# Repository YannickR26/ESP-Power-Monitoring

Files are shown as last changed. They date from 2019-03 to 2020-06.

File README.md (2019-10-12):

# ESP-Power-Monitoring
Power Monitoring based on ESP8266 and ATM90E32

## Hardware
ATM90E32 is a poly-phase energy metering ic, so 3 lines can be monitor

This board can be work in 2 mode :
  
  * 1 phase mode : 110V to 240V AC (up to 3 line)
  * 3 phase mode : 380V AC (use the 3 line)
 
[Here the schematic of this board](Hardware/Project%20Outputs%20for%20ESP-Power-Monitoring/Schematic%20Print/Schematic%20Prints.PDF)

And some pictures of this board

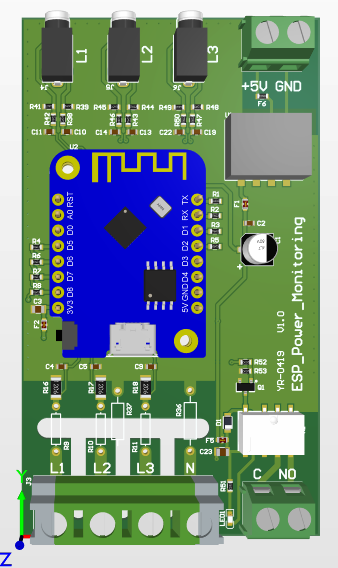
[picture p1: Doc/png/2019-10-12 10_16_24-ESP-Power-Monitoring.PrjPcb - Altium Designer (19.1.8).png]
top


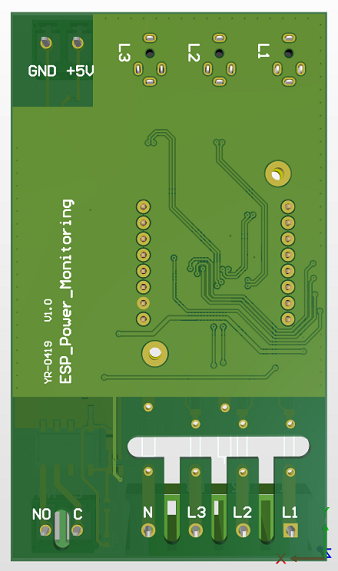
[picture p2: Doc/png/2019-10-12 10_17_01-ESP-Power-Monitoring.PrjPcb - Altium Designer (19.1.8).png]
bottom


This board can be mount on DIN rail

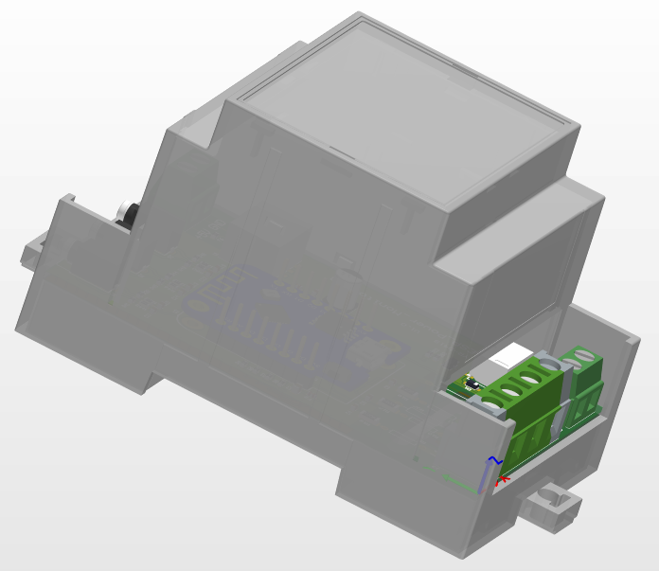
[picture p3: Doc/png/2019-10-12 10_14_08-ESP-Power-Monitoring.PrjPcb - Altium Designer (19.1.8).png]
din rail enclosure


## Software
Send data in MQTT at a fix configurable time

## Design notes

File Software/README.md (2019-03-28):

# ESP-Power-Monitoring
Power Monitoring based on ESP8266

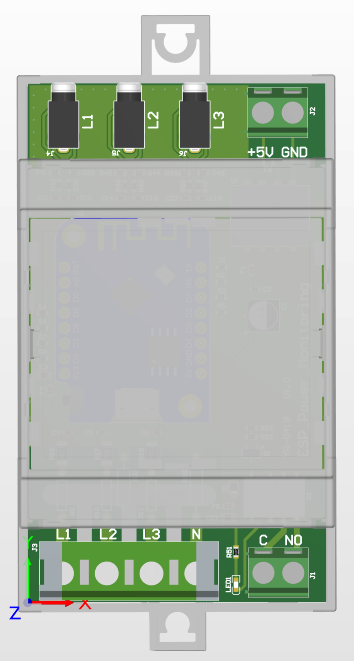
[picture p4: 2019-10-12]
Doc/png/2019-10-12 10_15_19-ESP-Power-Monitoring.PrjPcb - Altium Designer (19.1.8).png

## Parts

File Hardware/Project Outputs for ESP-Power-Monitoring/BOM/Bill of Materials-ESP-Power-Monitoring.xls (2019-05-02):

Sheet: BOM Report
Bill of Materials |  | Bill of Materials for Project [ESP-Power-Monitoring.PrjPcb] (No PCB Document Selected)
Source Data From: |  | ESP-Power-Monitoring.PrjPcb
Project: |  | ESP-Power-Monitoring.PrjPcb
Variant: |  | None
Creation Date: | 23/04/2019 | 9:58:00
Print Date: | 2019-04-23 | 10:09:58
Production Quantity: | 1
Currency | Euros (€)
Footprint | Comment | Designator | Quantity | Supplier 1 | Supplier Part Number 1 | Supplier Pricing 1 | Subtotal | MF | MPN | Farnell | Digi-Key
 | Boitier Rail DIN | B1 | 1 | Farnell | 2473160 | 3,62 € | 3.620 € | BUD INDUSTRIES | DMB4771 | 5
CAP_PANA_C | 100uF_10V_PANA_C | C1 | 1 | Farnell | 2807991 | 0,274 € | 0.274 € | PANASONIC ELECTRONIC COMPONENTS | EEE1AA101WR | 5
C0603 | 1uF_16V_0603 | C2 | 1 | Farnell | 2533943 | 0,0886€ | 0.089 € | WURTH ELEKTRONIK | 885012106017 | 10
C0805 | 10uF_6V3_0805 | C3, C12, C16, C17, C20, C21, C23 | 7 | Farnell | 1759476 | 0,28 € | 1.960 € | MULTICOMP | MCTT21X106M6R3CT | 40
C0603 | 18nF_16V_0603 | C4, C5, C6, C7, C8, C9, C10, C11, C13, C14, C19, C22 | 12 | Farnell | 1759006 | 0,0444 € | 0.533 € | MULTICOMP | MC0603B183K160CT | 60
C0603 | 100nF_10V_0603 | C15, C18 | 2 | Farnell | 2627427 | 0,0486 € | 0.097 € | MULTICOMP | MC0603B104K100CT | 10
TUMD2 | 100V_1A_TUMD2 | D1 | 1 | Farnell | 1864881 | 0,252€ | 0.252 € | VISHAY | MSE1PB-M3/89A | 5
EMIFIL_0603 | EMI | F1, F3, F4, F5, F6 | 5 | Farnell | 1686508 | 0,083 € | 0.415 € | MURATA | NFM18PC104R1C3D | 25
R0603 | 1A | F2 | 1 | Farnell | 2849996 | 0,101 € | 0.101 € | MULTICOMP | MCCFB0603TFF/1 | 10
691213710002 | 691213710002 | J1, J2 | 2 | Farnell | 2493614 | 0,308 € | 0.616 € | Wurth Elektronik | 691213710002 | 10
691242910004 | 691242910004 | J3 | 1 | Farnell | 2493618 | 0,839 € | 0.839 € | Wurth Elektronik | 691242910004 | 10
SJ1-2503A | SJ1-2503A | J4, J5, J6 | 3 | Digi-Key | CP1-2503A-ND | 0,60 € | 1.800 € | CUI Inc. | SJ1-2503A |  | 1
RELAY_G6K_2F_Y | Relay-DPDT | K1 | 1 | Digi-Key | Z2354-ND | 3,43 € | 3.430 € | Omron Electronics | G6K-2F-Y DC3 |  | 5
LED_0603_Bright Green | LED_Green | LED1 | 1 | Farnell | 2322073 | 0,189€ | 0.189 € | Wurth Elektronik | 150060VS75000 | 5
SOT23_N | 2.1A_40V_0R095 | Q1 | 1 | Farnell | 2469648 | 0,342€ | 0.342 € | NEXPERIA | PMV130ENEA | 5
R0603 | 22R_1%_0603 | R1, R2, R3, R4, R5, R6, R7, R8 | 8 | Farnell | 2447301 | 0,0056€ | 0.045 € | Multicomp | MCWR06X22R0FTL | 100
AXIAL-0.3 | 1M_1%_TRAD | R9, R11, R13 | 3 | Farnell | 1100281 | 0,102 € | 0.306 € | TT ELECTRONICS / WELWYN | MH25-1MJI | 20
R1206 | 1K_1%_1206 | R10, R12, R14 | 3 | Farnell | 9337008 | 0,0119 € | 0.036 € | MULTICOMP | MC0125W120651K | 20
R0603 | 1K_1%_0603 | R15, R16, R19, R20, R24, R25, R28, R29, R32 | 9 | Farnell | 1469740 | 0,0211€ | 0.190 € | VISHAY | CRCW06031K00FKEA | 100
AXIAL-0.4 | NC | R17, R18 | 2 |  |  |  | 0.000 €
R0603 | 2R4_1%_0603 | R21, R23, R26, R27, R30, R31 | 6 | Farnell | 2668257 | 0,0529 € | 0.317 € | WALSIN | WR06W2R40FTL | 30
R0603 | 10K_1%_0603 | R22, R35 | 2 | Farnell | 2447230 | 0,0056€ | 0.011 € | MULTICOMP | MCWR06X1002FTL | 100
R0603 | 220R_1%_0603 | R33, R34 | 2 | Farnell | 2447298 | 0,0059 € | 0.012 € | MULTICOMP | MCWR06X2200FTL | 100
R1SE | DC/DC_ISO | U1 | 1 | Farnell | 2484118 | 6,95 € | 6.950 € | XP POWER | ISH0503A |  | 5
WEMOS_D1_MINI | Wemos_D1_Mini | U2 | 1 |  |  |  | 0.000 €
TQFP48 | ATM90E32AS | U3 | 1 | Farnell | 2857740 | 2,17 € | 2.170 € | MICROCHIP | ATM90E32AS-AU-R | 5
OSC_3.2X2.5 | 16.384MHz | Y1 | 1 | Farnell | 2853939 | 0,159€ | 0.159 € | MULTICOMP | MCSJK-7U-16.384-10-30-80-B-30 | 5
Total |  |  | 79 |  |  |  | 24.752 €
Approved |  | Notes

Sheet: Project Information
Project Full Path | D:\Git\mle-ModuleIPCan\Hard\V1.2\Project\ModuleIPCan\ModuleIPCan.PrjPcb
Project Filename | ModuleIPCan.PrjPcb
Variant Name | None
Data-Source Filename | ModuleIPCan.PrjPcb
Data-Source Full Path | D:\Git\mle-ModuleIPCan\Hard\V1.2\Project\ModuleIPCan\ModuleIPCan.PrjPcb
Title | Top
Total Quantity | 268
Report Time | 16:41:35
Report Date | 27/09/2016
Report Date & Tine | 27/09/2016 16:41:35
Output Name | Bill of Materials
Output Type | BOM_PartType
Output Generator Name | BOM
Output Generator Description | Bill of Materials

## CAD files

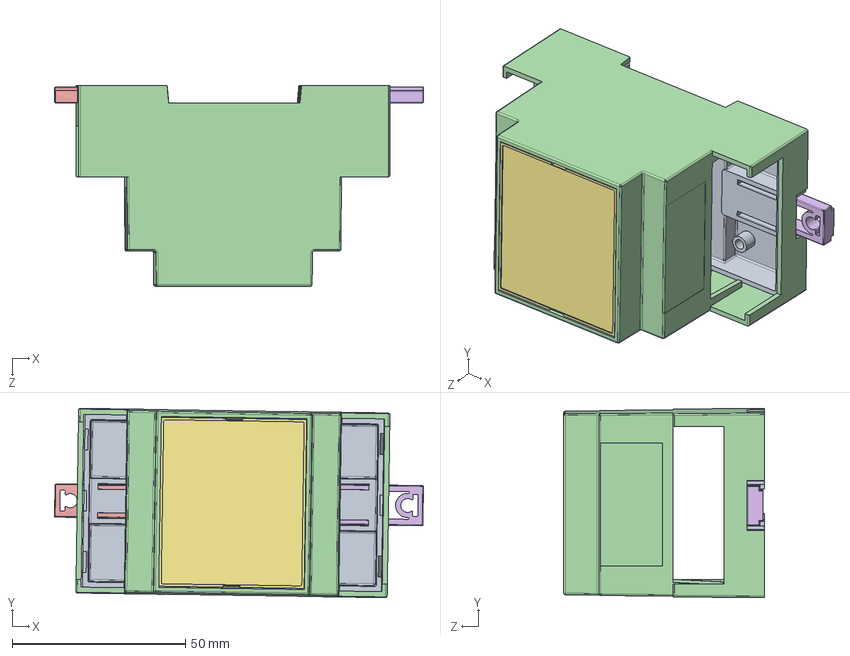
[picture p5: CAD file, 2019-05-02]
Hardware/cnmb_3_kit.STEP
106.6 x 54.7 x 58.0 mm
cnmb_3_kit_01
cnmb_3_kit_02
cnmb_3_kit_03
cnmb_3_kit_04
cnmb_3_kit_05
cnmb_3_kit_06
cnmb_3_kit_07
cnmb_3_kit_08
cnmb_3_kit_09
cnmb_3_kit_10
cnmb_3_kit_13

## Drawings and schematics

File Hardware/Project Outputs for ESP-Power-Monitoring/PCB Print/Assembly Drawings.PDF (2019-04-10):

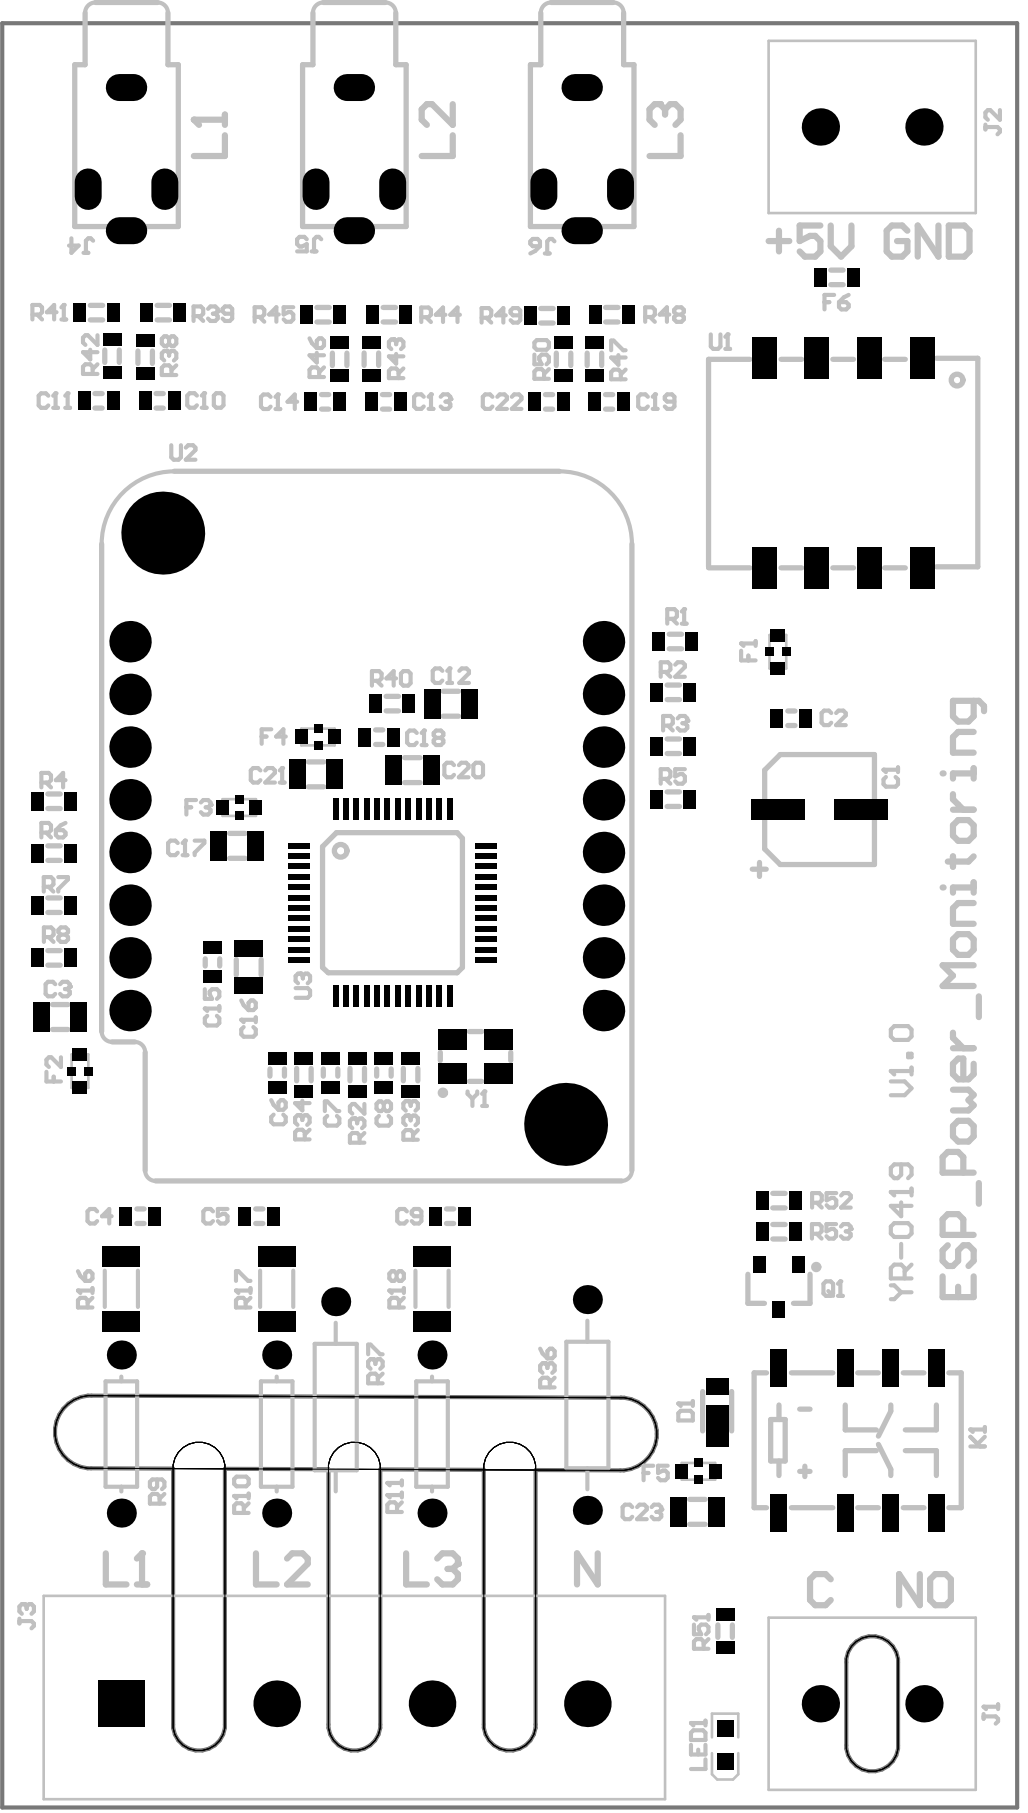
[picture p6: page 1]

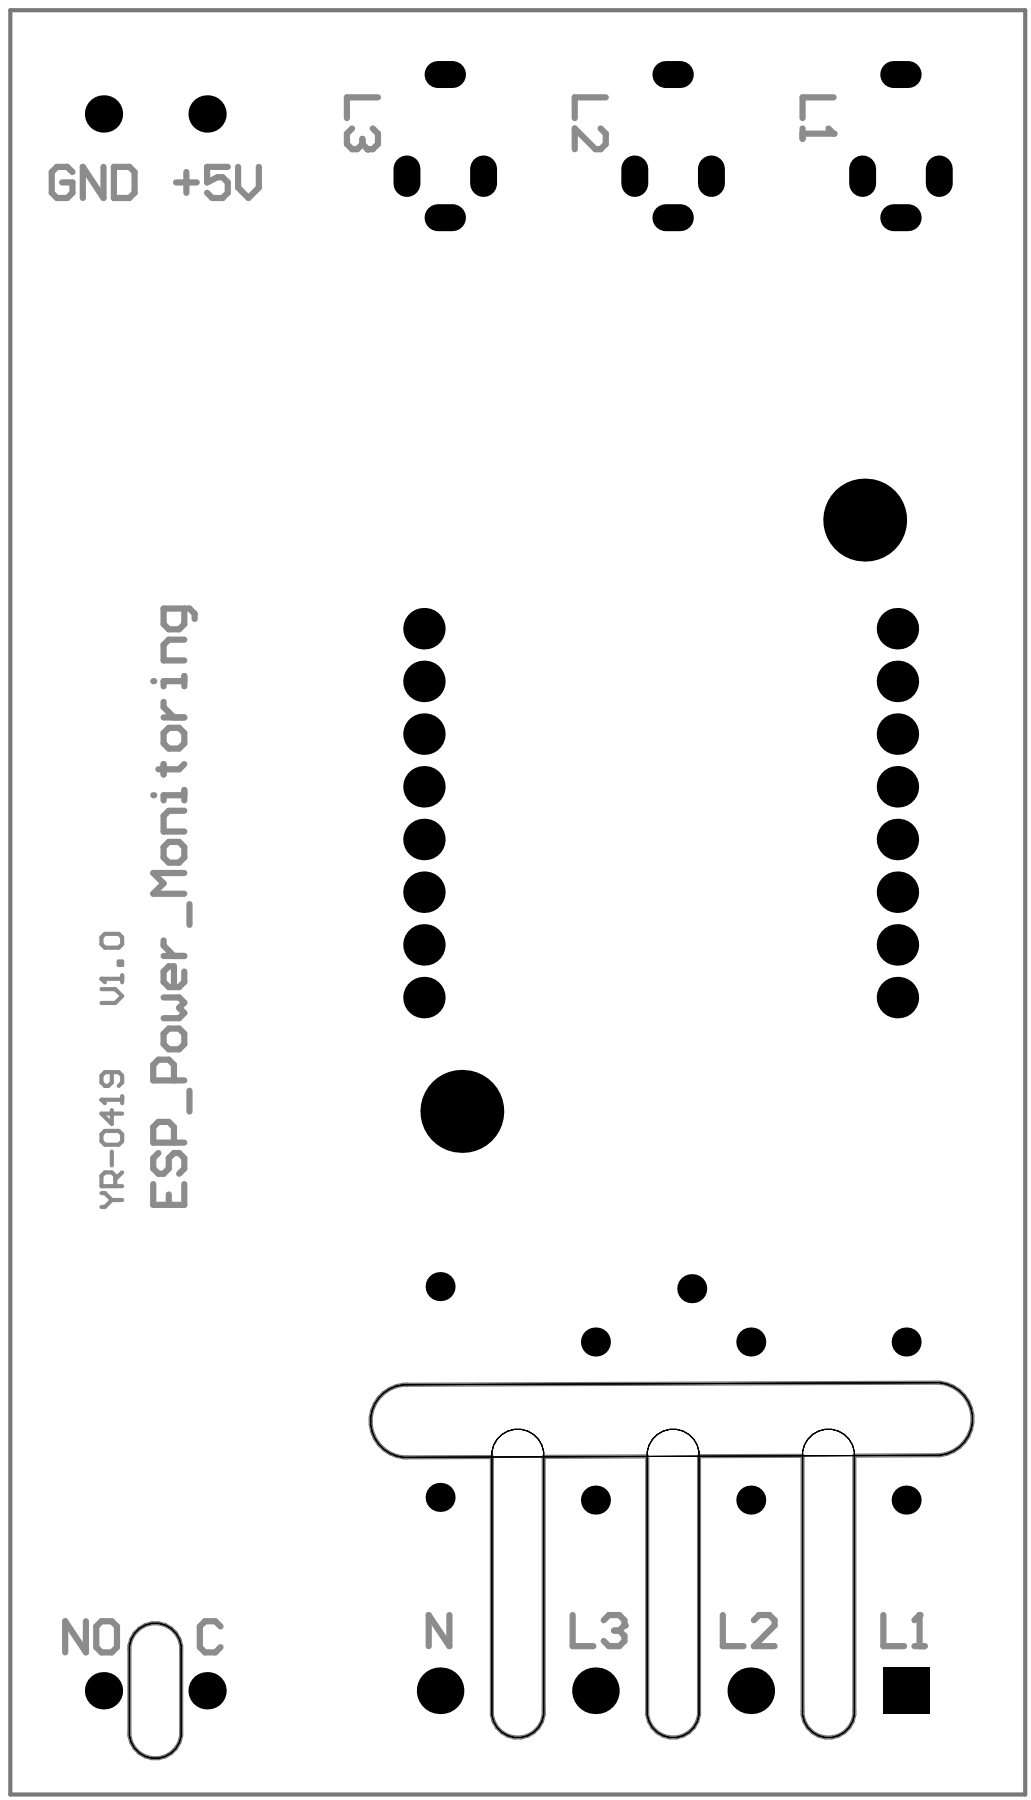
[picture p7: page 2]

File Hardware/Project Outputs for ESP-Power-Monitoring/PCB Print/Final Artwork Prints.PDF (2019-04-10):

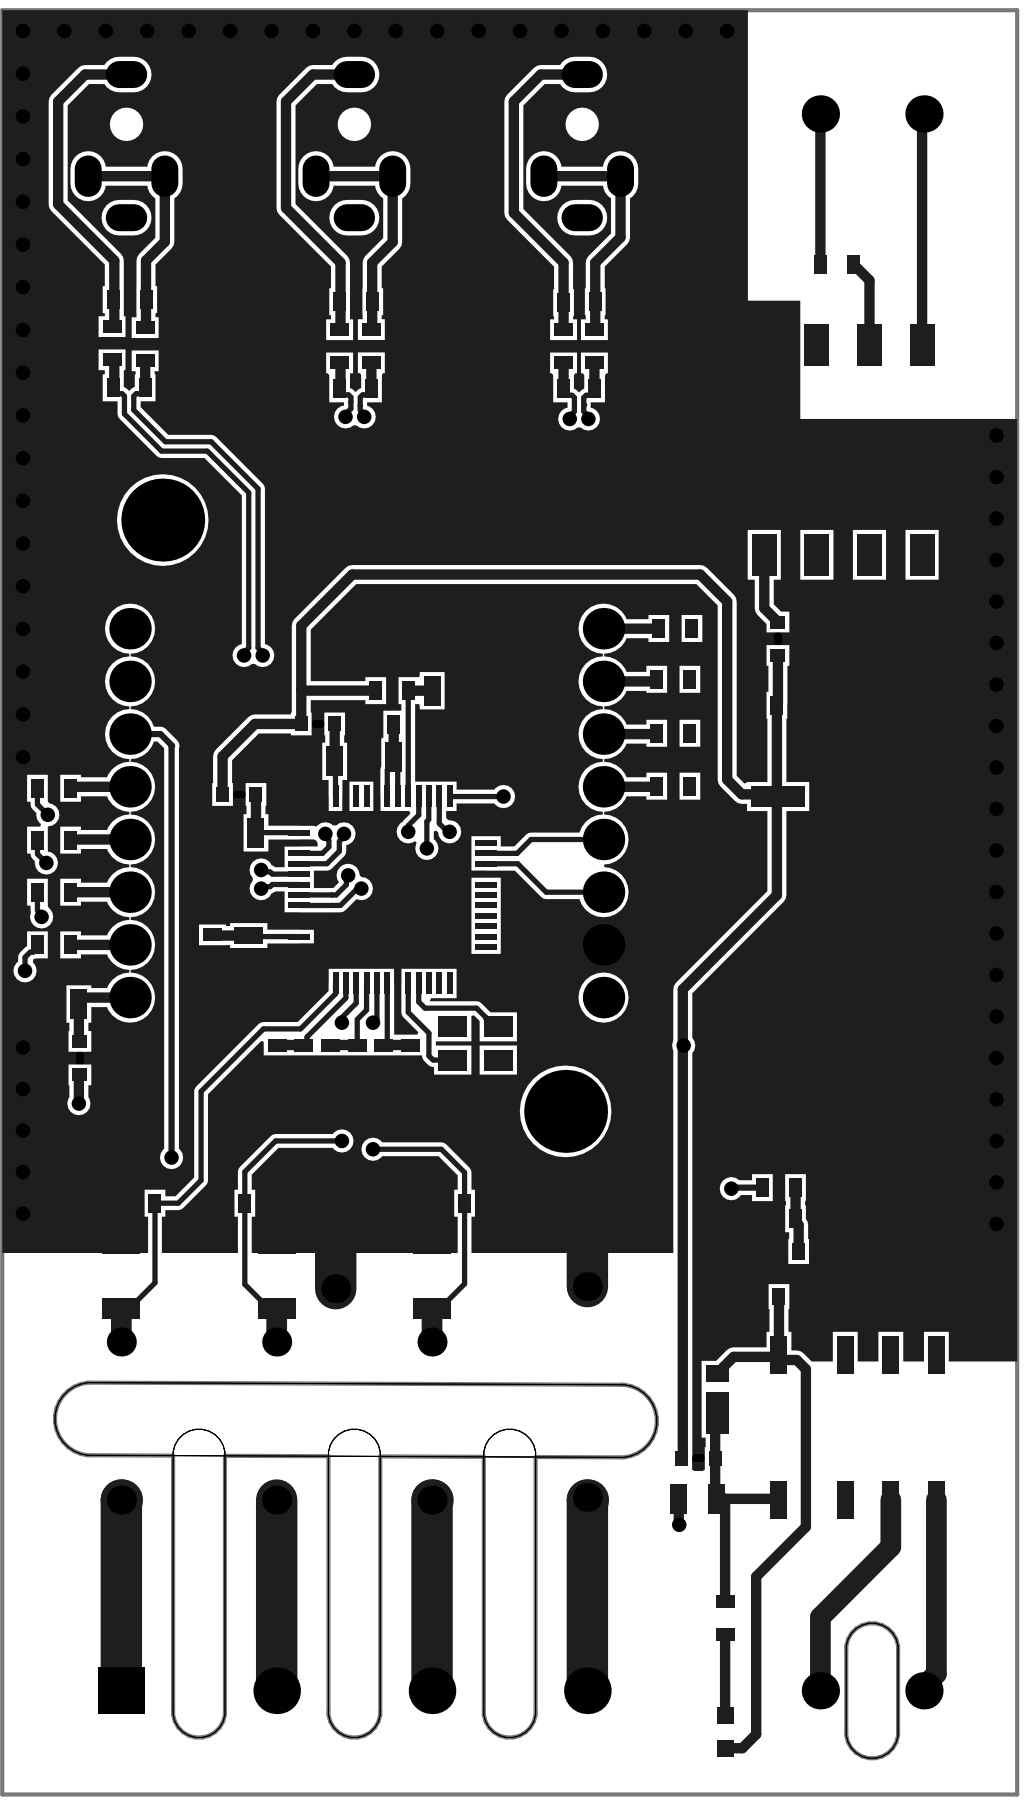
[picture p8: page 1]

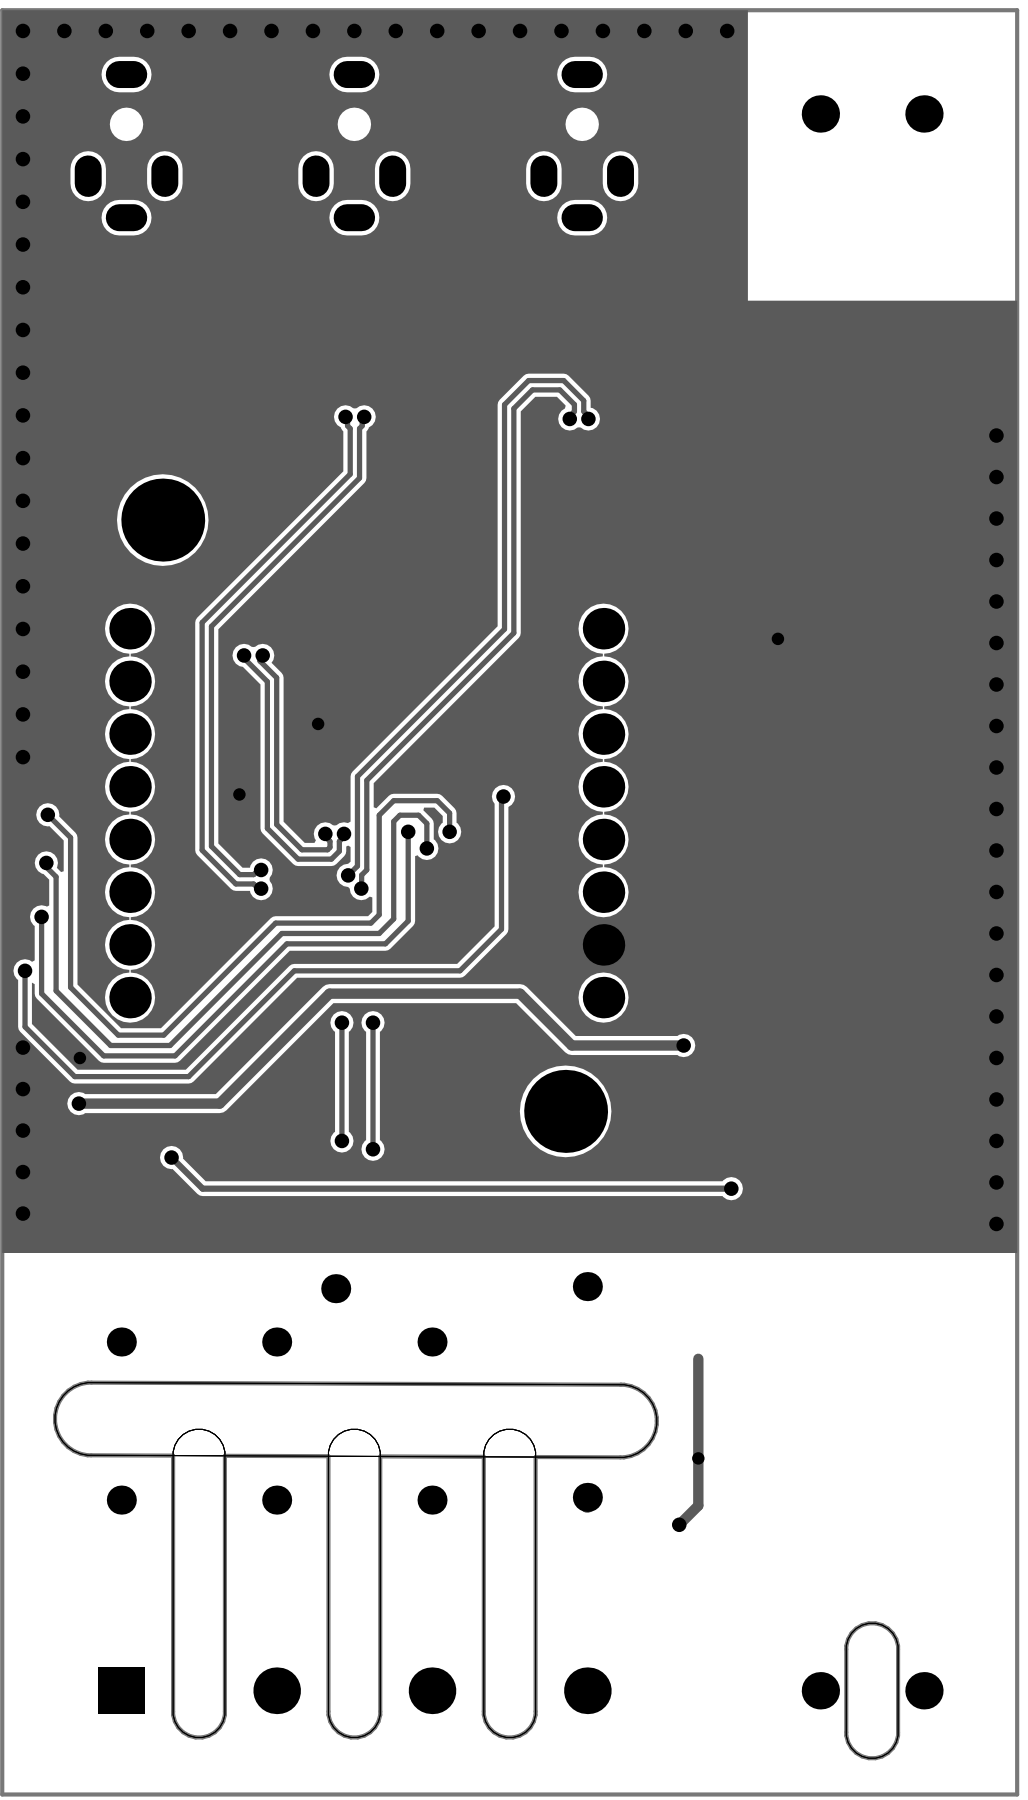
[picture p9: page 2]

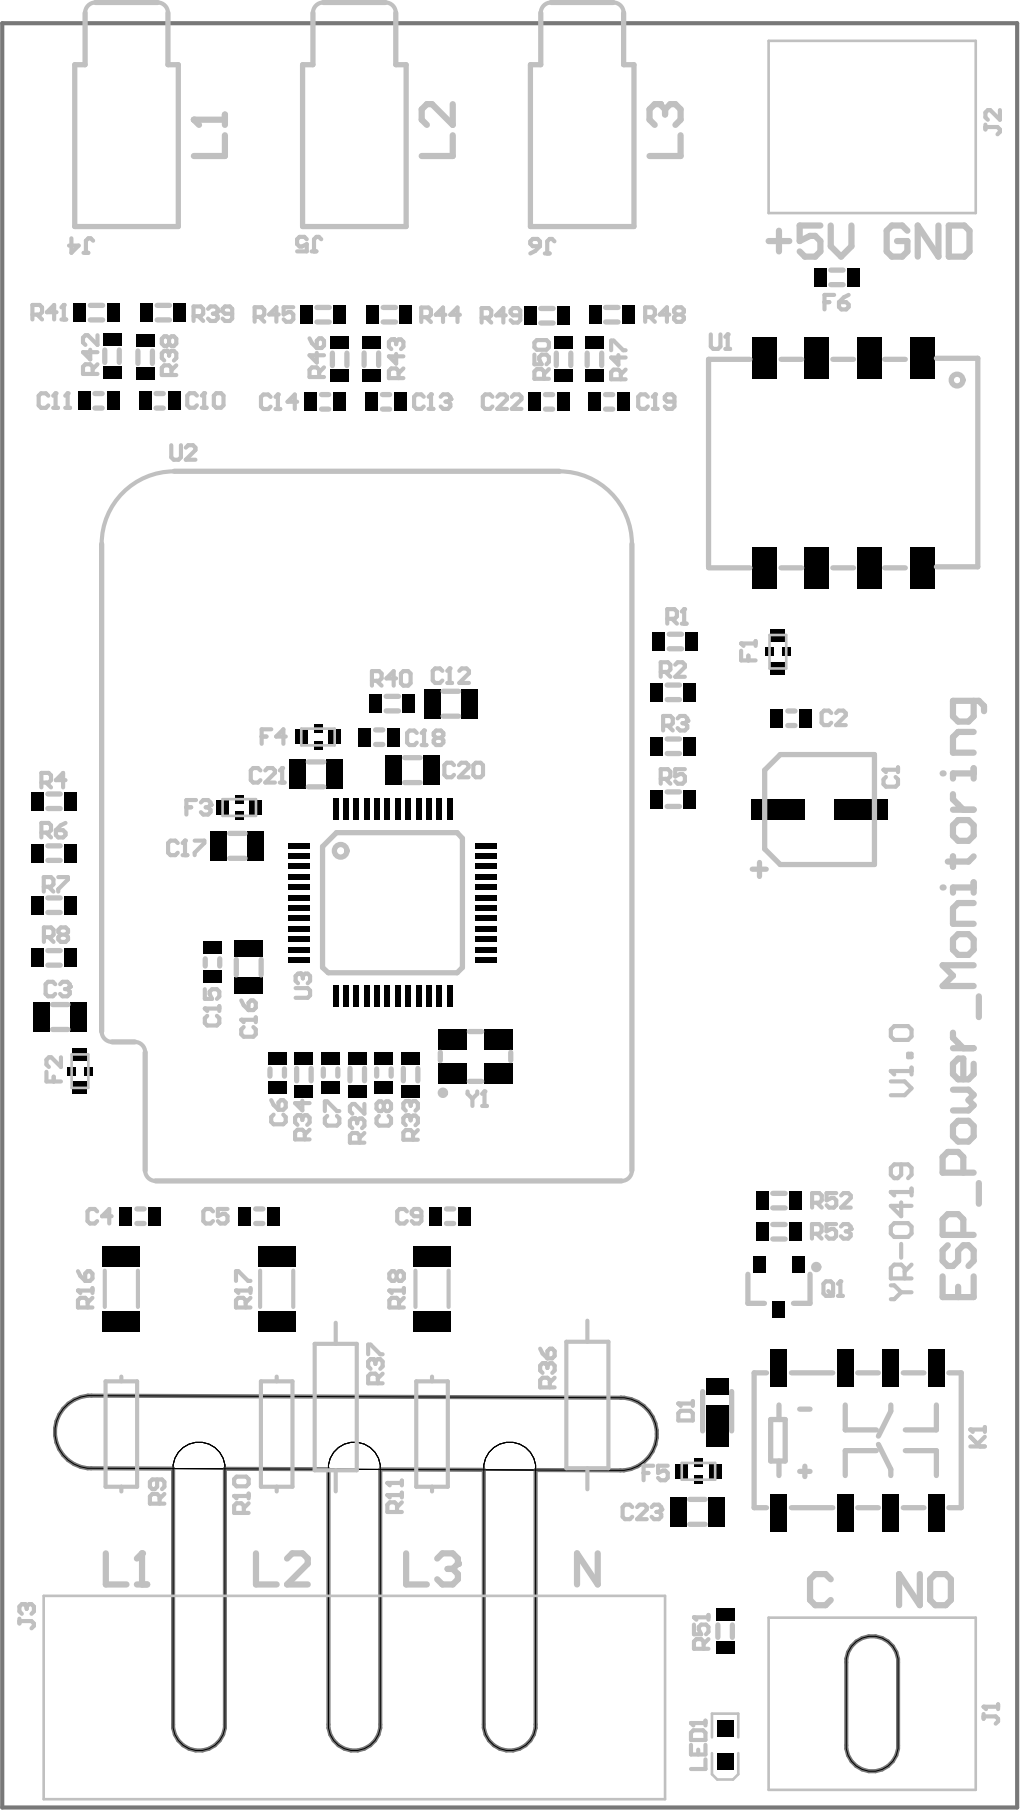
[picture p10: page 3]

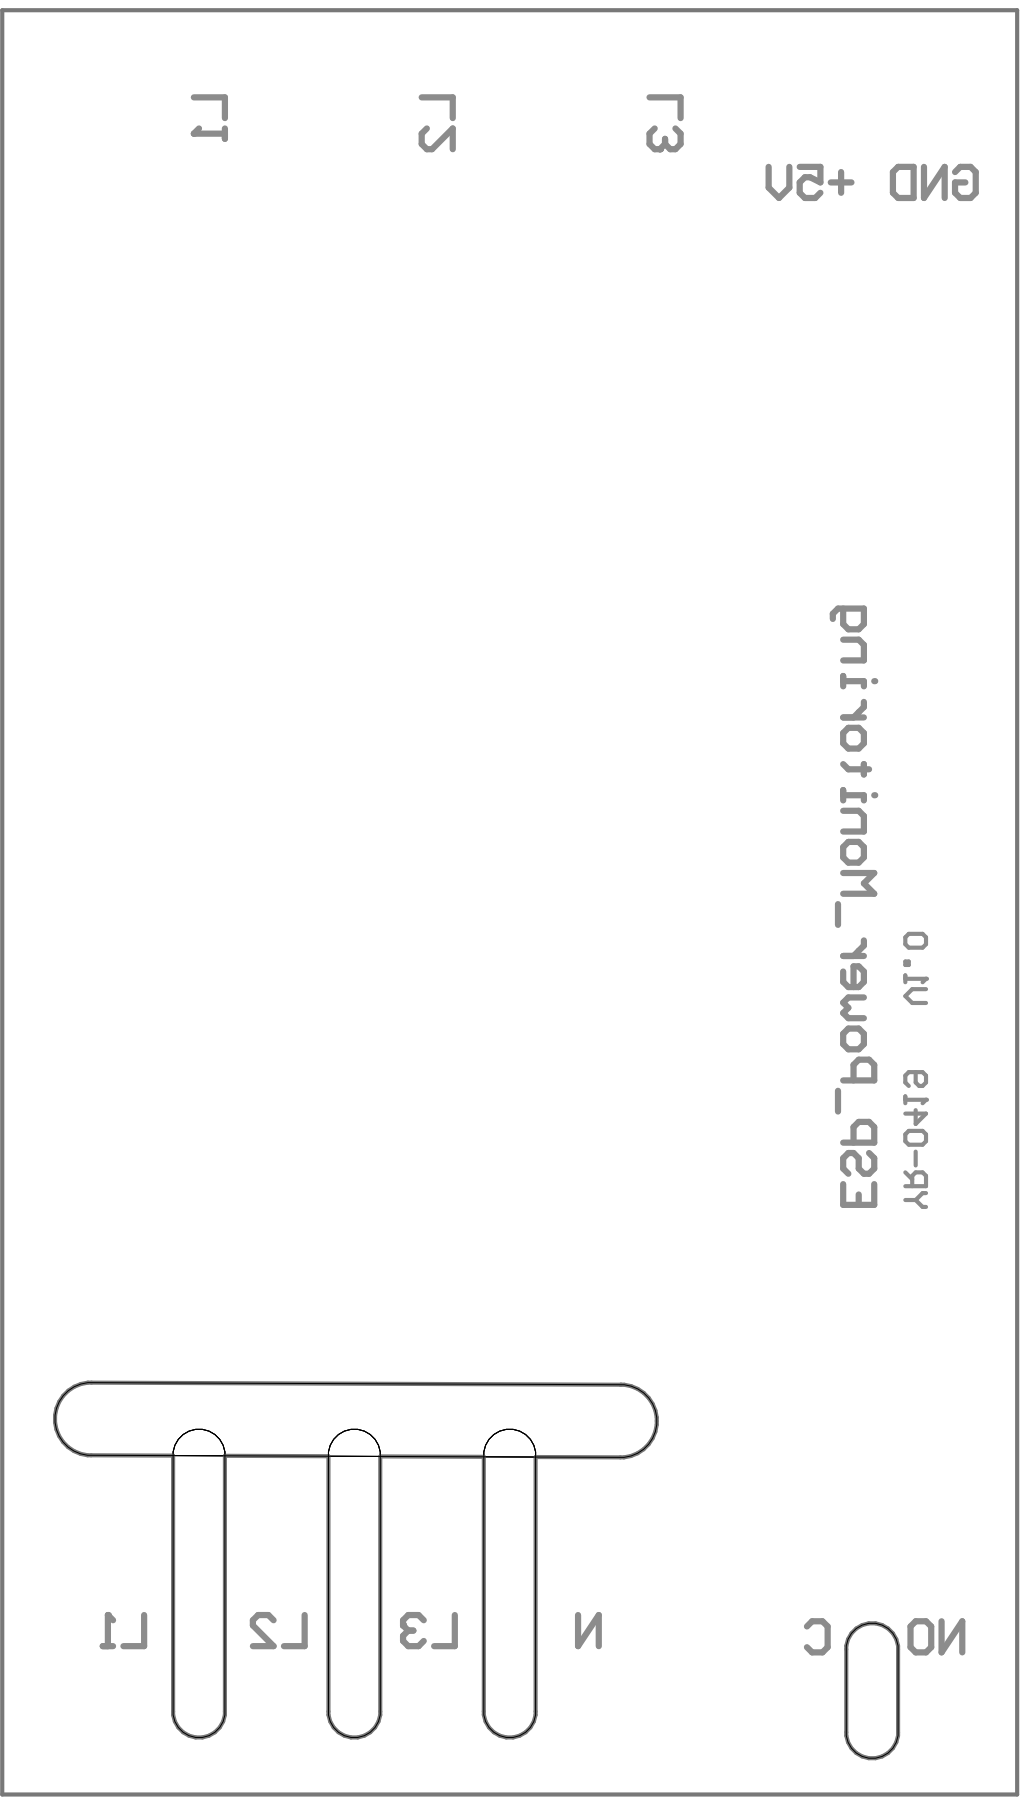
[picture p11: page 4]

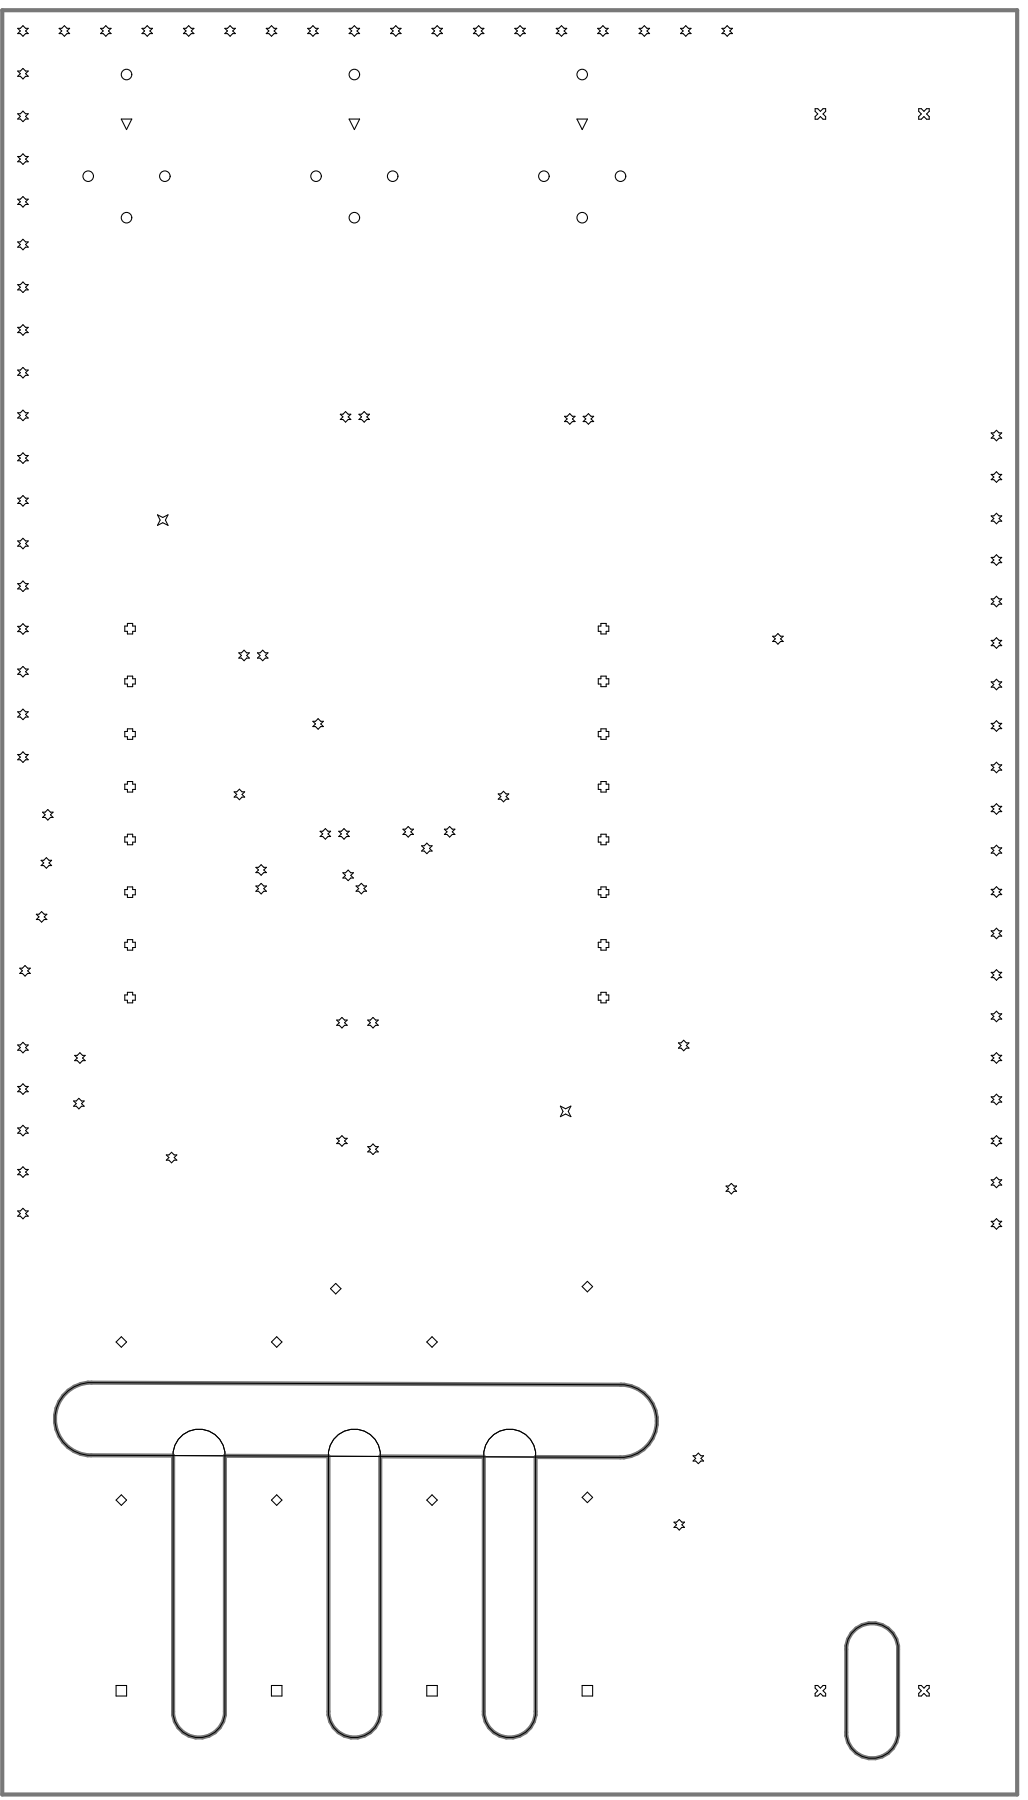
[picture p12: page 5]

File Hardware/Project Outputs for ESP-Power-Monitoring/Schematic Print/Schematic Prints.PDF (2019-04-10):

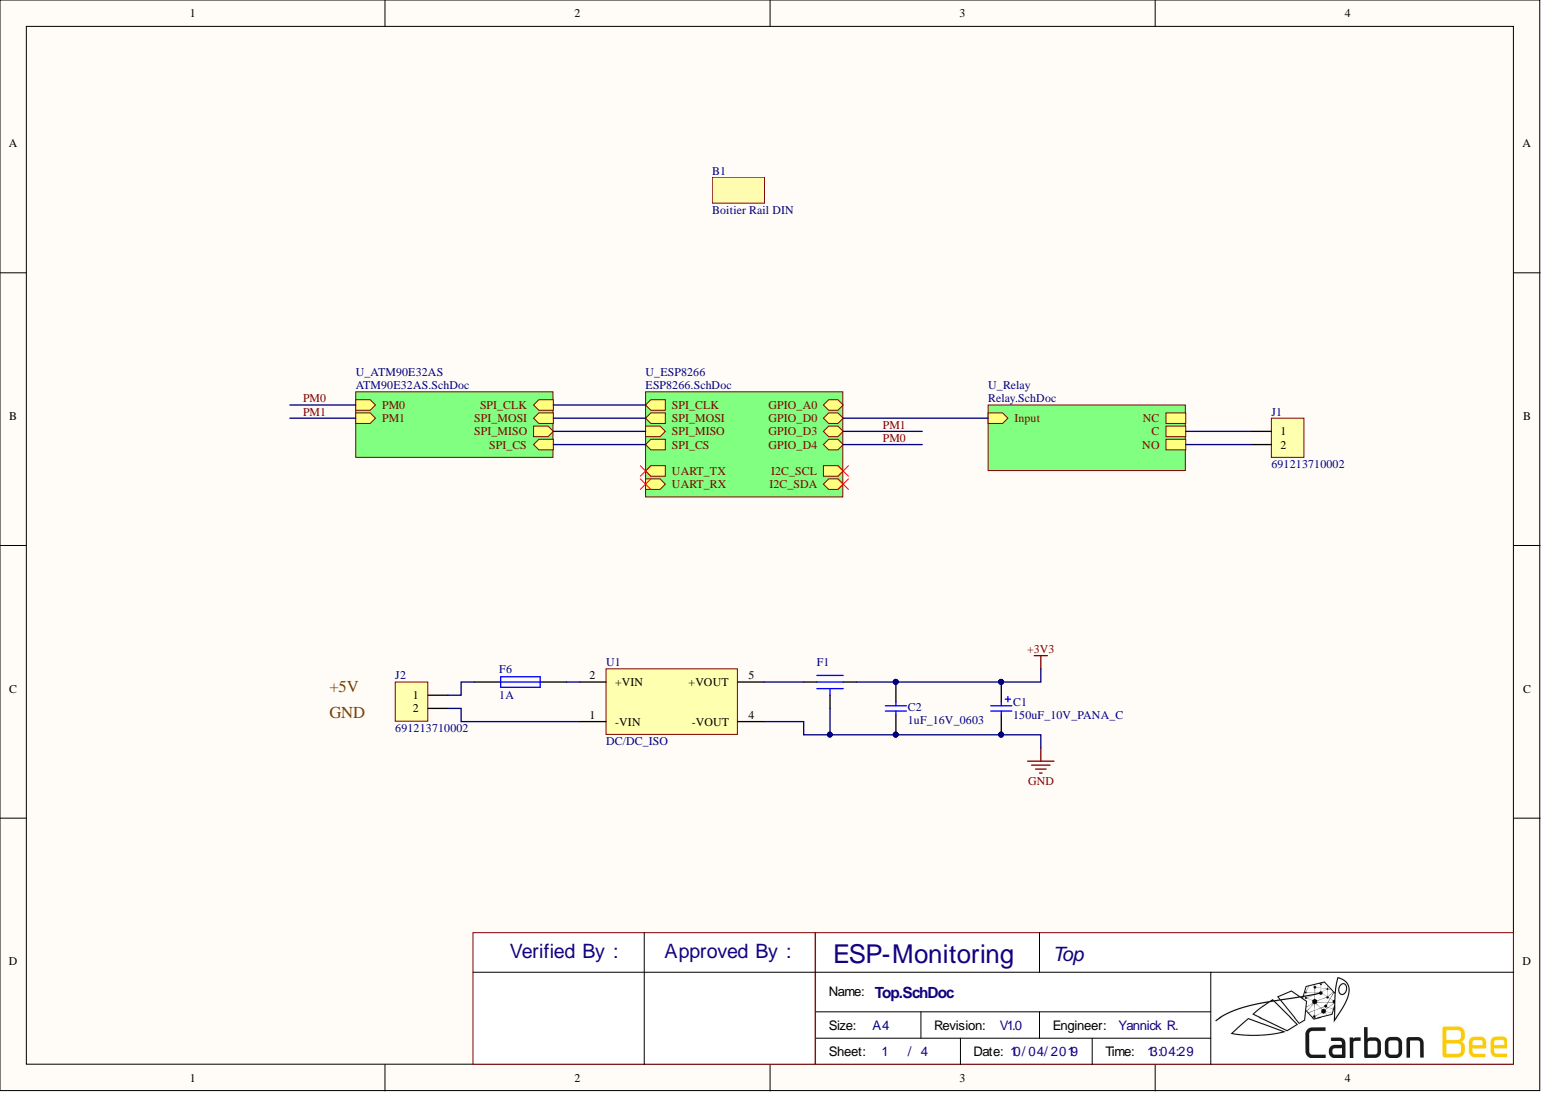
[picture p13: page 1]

Verified By : | Approved By : | ESP-Monitoring | Top

Name: Top.SchDoc

Size: A4 | Revision: V1.0 | Engineer: Yannick R.

Sheet: 1 / 4 | Date: 10/ 04/ 2019 | Time: 13:04:29

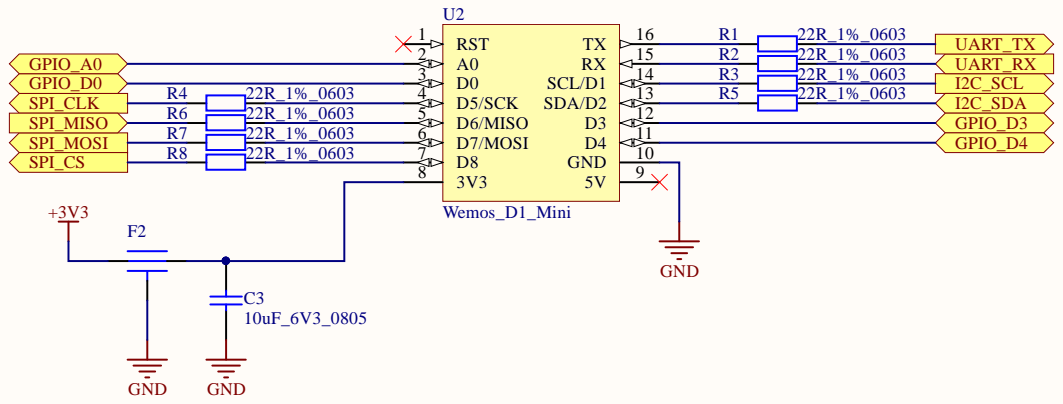
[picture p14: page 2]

Ve rifie d B y : | A p p r o v e d B y : | E S P -M onit o ring | µ Co n t ro lle r ESP8 2 6 6

S i z e : A | Revi s i o n : V1 . | E n g i n e e r : Ya n n i ck R .

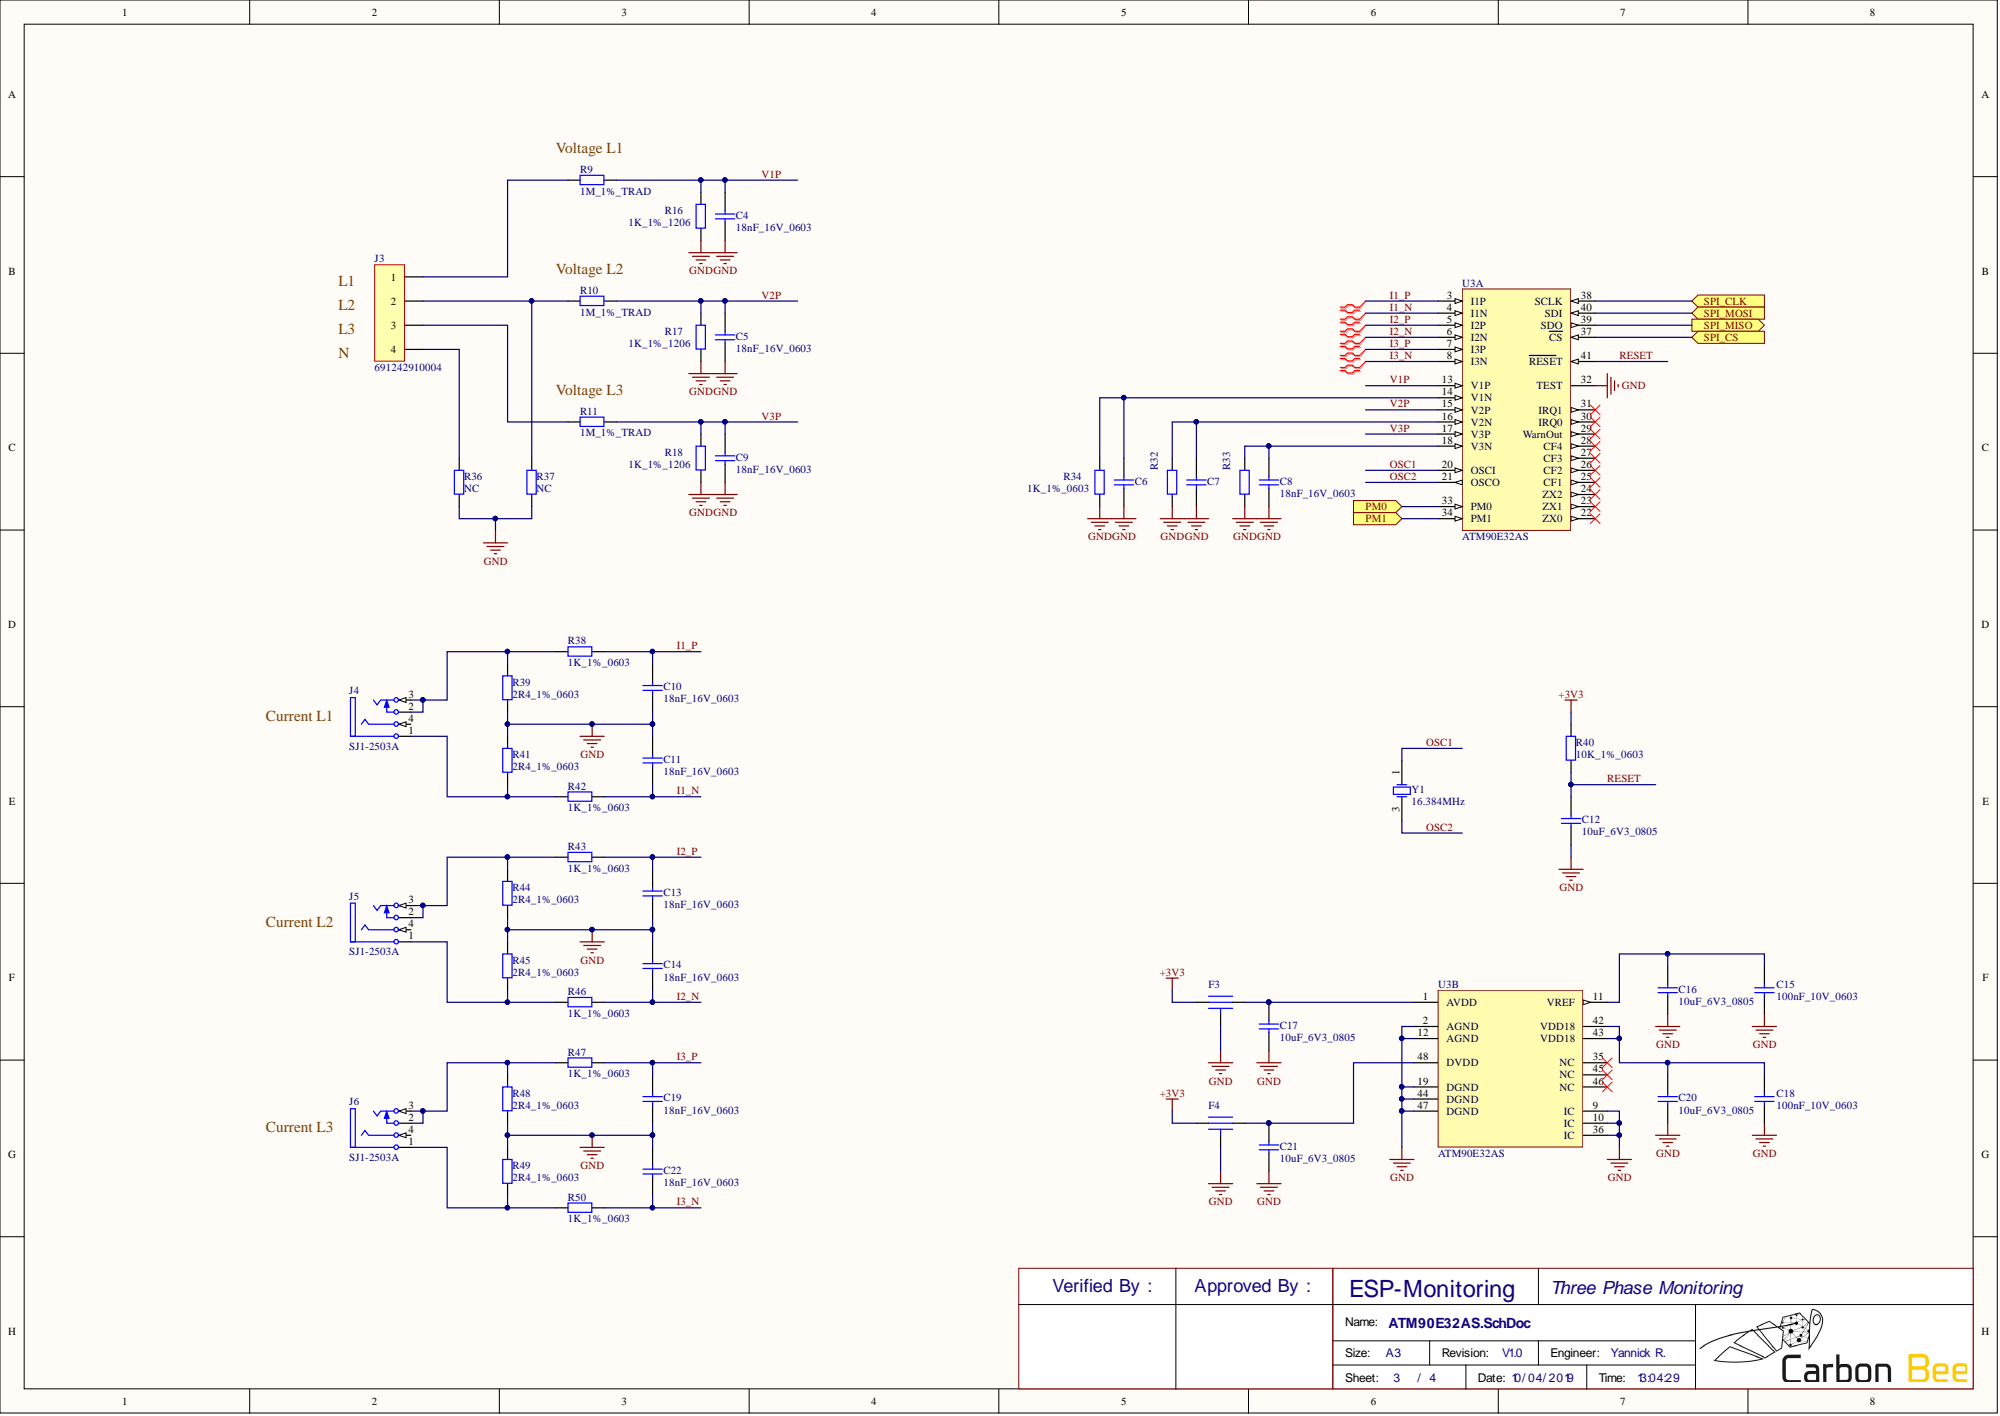
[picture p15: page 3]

Vol

4 4
4 7

1 0
3 6

Ve rifie d B y : | A p p r o v e d B y : | E S P -M onit o ring | Th re e Ph a s e Mo nit o rin g

N a m e : ATM9 0 E 3 2 A S . S ch D oc

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

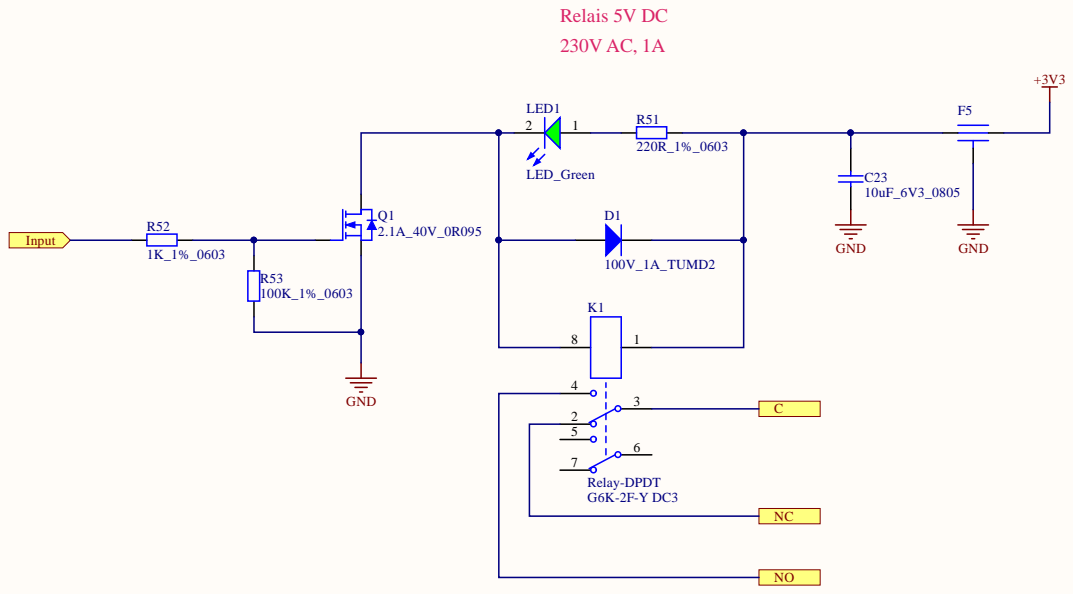
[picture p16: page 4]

Verified By : | Approved By : | ESP-Monitoring | Relais 5V

Name: Relay.SchDoc

Size: A4 | Revision: V1.0 | Engineer: Yannick R.

Sheet: 4 / 4 | Date: 10/ 04/ 2019 | Time: 13:04:30

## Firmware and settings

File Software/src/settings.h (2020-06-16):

#pragma once

// Version
#define VERSION                     "V1.7.0"

#define DEFAULT_HOSTNAME            "ESP_Monitoring"
#define DEFAULT_MQTTIPSERVER        "192.168.1.201"
#define DEFAULT_MQTTPORTSERVER      1883

#define DEFAULT_SAVE_DATA_INTERVAL_SEC  (1 * 3600)  // Update time from NTP server and save data every 1 hours
#define DEFAULT_SEND_DATA_INTERVAL_SEC      5       // Send data every 5 secondes
#define DEFAULT_CURRENT_CLAMP               30      // 30A current clamp by default

// Mode
#define MODE_MONO   0
#define MODE_TRI_1  1
#define MODE_TRI_2  2
#define MODE_DEBUG  3

// ATM90E32
#define ATM90E32_CS         D8
#define ATM90E32_PM0        D4
#define ATM90E32_PM1        D3
#define ATM90E32_UGAIN      30000
#define ATM90E32_IGAIN      300     // x capacité de la pince amperemetrique (defaut 30A)

// Relay
#define RELAY_PIN       D0

// LED
#define LED_PIN             LED_BUILTIN
#define LED_TIME_NOMQTT     100
#define LED_TIME_WORK       500

// Timezone
#define UTC_OFFSET      +1

// change for different ntp (time servers)
#define NTP_SERVERS "0.fr.pool.ntp.org", "time.nist.gov", "pool.ntp.org"

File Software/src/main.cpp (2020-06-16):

#include <Arduino.h>
#include <WiFiManager.h>
#include <Ticker.h>

#include "JsonConfiguration.h"
#include "HttpServer.h"
#include "ATM90E32.h"
#include "Mqtt.h"
#include "settings.h"
#include "Logger.h"

static Ticker tick_blinker, tick_sendData, tick_saveData;

// OTA
#ifdef ENABLE_OTA
#include <ArduinoOTA.h>
#endif

/**************/
/*** TICKER ***/
/**************/

// Update time from NTP and save data
void updateTimeAndSaveData()
{
  Log.println("Update NTP");
  configTime(UTC_OFFSET * 3600, 0, NTP_SERVERS);
  delay(500);
  while (!time(nullptr))
  {
    Log.print("#");
    delay(1000);
  }

  Log.println("Save data");
  Configuration._consoA = Monitoring.getLineA().conso;
  Configuration._consoB = Monitoring.getLineB().conso;
  Configuration._consoC = Monitoring.getLineC().conso;
  Configuration.saveConfig();

  tick_saveData.once(Configuration._timeSaveData, updateTimeAndSaveData);
}

// LED blink
void blinkLED()
{
  digitalWrite(LED_PIN, !digitalRead(LED_PIN));

  // Check state of MQTT
  if (MqttClient.isConnected())
  {
    tick_blinker.once_ms(LED_TIME_WORK, blinkLED);
  }
  else
  {
    tick_blinker.once_ms(LED_TIME_NOMQTT, blinkLED);
  }
}

// Send Data to MQTT
void sendData()
{
  Log.println("Read data...");
  Monitoring.handle();

  Log.println("Send data to MQTT");
  MqttClient.publishMonitoringData();

  tick_sendData.once(Configuration._timeSendData, sendData);
}

/*************/
/*** SETUP ***/
/*************/

// Wifi setup
void wifiSetup()
{
  WiFiManager wifiManager;
  wifiManager.setDebugOutput(false);
  // wifiManager.resetSettings();

  // WiFiManagerParameter
  WiFiManagerParameter custom_mqtt_hostname("hostname", "hostname", Configuration._hostname.c_str(), 60);
  WiFiManagerParameter custom_mqtt_server("mqttIpServer", "mqtt ip", Configuration._mqttIpServer.c_str(), 40);
  WiFiManagerParameter custom_mqtt_port("mqttPortServer", "mqtt port", String(Configuration._mqttPortServer).c_str(), 6);
  WiFiManagerParameter custom_time_update("timeSendData", "intervale d'envoie des données (s)", String(Configuration._timeSendData).c_str(), 6);
  WiFiManagerParameter custom_mode("mode", "mode", String(Configuration._mode).c_str(), 1);
  WiFiManagerParameter custom_currentA("currentClampA", "capacité de la pince amperemetrique A (A)", String(Configuration._currentClampA).c_str(), 3);
  WiFiManagerParameter custom_currentB("currentClampB", "capacité de la pince amperemetrique B (A)", String(Configuration._currentClampB).c_str(), 3);
  WiFiManagerParameter custom_currentC("currentClampC", "capacité de la pince amperemetrique C (A)", String(Configuration._currentClampC).c_str(), 3);

  // add all your parameters here
  wifiManager.addParameter(&custom_mqtt_hostname);
  wifiManager.addParameter(&custom_mqtt_server);
  wifiManager.addParameter(&custom_mqtt_port);
  wifiManager.addParameter(&custom_time_update);
  wifiManager.addParameter(&custom_mode);
  wifiManager.addParameter(&custom_currentA);
  wifiManager.addParameter(&custom_currentB);
  wifiManager.addParameter(&custom_currentC);

  Log.println("Try to connect to WiFi...");
  // wifiManager.setWiFiChannel(6);
  wifiManager.setConfigPortalTimeout(300); // Set Timeout for portal configuration to 120 seconds
  if (!wifiManager.autoConnect(Configuration._hostname.c_str()))
  {
    Log.println("failed to connect and hit timeout");
    delay(3000);
    //reset and try again, or maybe put it to deep sleep
    ESP.reset();
    delay(5000);
  }

  Log.println(String("Connected to ") + WiFi.SSID());
  Log.println(String("IP address: ") + WiFi.localIP().toString());

  /* Get configuration from WifiManager */
  Configuration._hostname = custom_mqtt_hostname.getValue();
  Configuration._mqttIpServer = custom_mqtt_server.getValue();
  Configuration._mqttPortServer = atoi(custom_mqtt_port.getValue());
  Configuration._timeSendData = atoi(custom_time_update.getValue());
  Configuration._mode = atoi(custom_mode.getValue());
  Configuration._currentClampA = atoi(custom_currentA.getValue());
  Configuration._currentClampB = atoi(custom_currentB.getValue());
  Configuration._currentClampC = atoi(custom_currentC.getValue());
  Configuration.saveConfig();
}

// Setup
void setup()
{
  delay(100);

  /* Initialize Logger */
  Log.setup();
  Log.println();
  Log.println("==========================================");
  Log.println(String(F("=== ESP_Power_Monitoring ===")));
  Log.println(String(F("  Version: ")) + F(VERSION));
  Log.println(String(F("  Build: ")) + F(__DATE__) + " " + F(__TIME__));
  Log.println("==========================================");
  Log.println();

  pinMode(RELAY_PIN, OUTPUT);
  pinMode(LED_PIN, OUTPUT);

  /* Read configuration from SPIFFS */
  Configuration.setup();
  // Configuration.restoreDefault();

  wifiSetup();

  /* Initialize the ATM90E32 + SPI port */
  Monitoring.begin(ATM90E32_CS, ATM90E32_PM0, ATM90E32_PM1, Configuration._mode, 0, ATM90E32_UGAIN, Configuration._currentClampA, Configuration._currentClampB, Configuration._currentClampC);
  Monitoring.setConsoLineA(Configuration._consoA);
  Monitoring.setConsoLineB(Configuration._consoB);
  Monitoring.setConsoLineC(Configuration._consoC);

  /* Initialize HTTP Server */
  HTTPServer.setup();

  /* Initialize MQTT Client */
  MqttClient.setup();

  // Init OTA
#ifdef ENABLE_OTA
  Log.println("Arduino OTA activated");

  // Port defaults to 8266
  ArduinoOTA.setPort(8266);

  // Hostname defaults to esp8266-[ChipID]
  ArduinoOTA.setHostname(Configuration._hostname.c_str());

  ArduinoOTA.onStart([&]() {
    Log.println("Arduino OTA: Start updating");
  });
  ArduinoOTA.onEnd([]() {
    Log.println("Arduino OTA: End");
  });
  ArduinoOTA.onProgress([](unsigned int progress, unsigned int total) {
    Log.printf("Arduino OTA Progress: %u%%\r", (progress / (total / 100)));
  });
  ArduinoOTA.onError([](ota_error_t error) {
    Log.printf("Arduino OTA Error[%u]: ", error);
    if (error == OTA_AUTH_ERROR)
      Log.println("Arduino OTA: Auth Failed");
    else if (error == OTA_BEGIN_ERROR)
      Log.println("Arduino OTA: Begin Failed");
    else if (error == OTA_CONNECT_ERROR)
      Log.println("Arduino OTA: Connect Failed");
    else if (error == OTA_RECEIVE_ERROR)
      Log.println("Arduino OTA: Receive Failed");
    else if (error == OTA_END_ERROR)
      Log.println("Arduino OTA: End Failed");
  });

  ArduinoOTA.begin();
  Log.println("");
#endif

  updateTimeAndSaveData();

  // Create ticker for blink LED
  tick_blinker.once_ms(LED_TIME_NOMQTT, blinkLED);

  // Create ticker for send Data to MQTT
  if (Configuration._timeSendData == 0)
    Configuration._timeSendData = 1;
  tick_sendData.once(Configuration._timeSendData, sendData);

  // Create ticker for update NTP and save data
  if (Configuration._timeSaveData == 0)
    Configuration._timeSaveData = 1;
  tick_saveData.once(Configuration._timeSaveData, updateTimeAndSaveData);
}

/************/
/*** LOOP ***/
/************/
void loop()
{
  static unsigned long tickPrintData;
  unsigned long currentMillis = millis();

  MqttClient.handle();
  Log.handle();
  HTTPServer.handle();

#ifdef ENABLE_OTA
  ArduinoOTA.handle();
#endif

  if ((currentMillis - tickPrintData) >= 1000)
  {
    /* Uncomment if you want calculate the offset of I and U
      ! Warning ! the voltage and the current must be at 0
    */
    // Log.println("Offset IA: " + String(Monitoring.CalculateVIOffset(IrmsA, IrmsALSB, IoffsetA)) + " (0x" + String((unsigned short)Monitoring.CalculateVIOffset(IrmsA, IrmsALSB, IoffsetA), HEX) + ")");
    // Log.println("Offset IB: " + String(Monitoring.CalculateVIOffset(IrmsB, IrmsBLSB, IoffsetB)) + " (0x" + String((unsigned short)Monitoring.CalculateVIOffset(IrmsB, IrmsBLSB, IoffsetB), HEX) + ")");
    // Log.println("Offset IC: " + String(Monitoring.CalculateVIOffset(IrmsC, IrmsCLSB, IoffsetC)) + " (0x" + String((unsigned short)Monitoring.CalculateVIOffset(IrmsC, IrmsCLSB, IoffsetC), HEX) + ")");

    // Log.println("Offset UA: " + String(Monitoring.CalculateVIOffset(UrmsA, UrmsALSB, UoffsetA)) + " (0x" + String((unsigned short)Monitoring.CalculateVIOffset(UrmsA, UrmsALSB, UoffsetA), HEX) + ")");
    // Log.println("Offset UB: " + String(Monitoring.CalculateVIOffset(UrmsB, UrmsBLSB, UoffsetB)) + " (0x" + String((unsigned short)Monitoring.CalculateVIOffset(UrmsB, UrmsBLSB, UoffsetB), HEX) + ")");
    // Log.println("Offset UC: " + String(Monitoring.CalculateVIOffset(UrmsC, UrmsCLSB, UoffsetC)) + " (0x" + String((unsigned short)Monitoring.CalculateVIOffset(UrmsC, UrmsCLSB, UoffsetC), HEX) + ")");
    if (Configuration._mode == MODE_DEBUG)
    {
      Log.println("Line A: " + String(Monitoring.GetLineVoltageA()) + "V, " + String(Monitoring.GetLineCurrentA()) + "A, " + String(Monitoring.GetActivePowerA()) + "W");
      Log.println("Line B: " + String(Monitoring.GetLineVoltageB()) + "V, " + String(Monitoring.GetLineCurrentB()) + "A, " + String(Monitoring.GetActivePowerB()) + "W");
      Log.println("Line C: " + String(Monitoring.GetLineVoltageC()) + "V, " + String(Monitoring.GetLineCurrentC()) + "A, " + String(Monitoring.GetActivePowerC()) + "W");
      Log.println("Frequency: " + String(Monitoring.GetFrequency()) + "Hz");
      Log.println("Total Active Fond Power: " + String(Monitoring.GetTotalActiveFundPower()) + "W");
      Log.println("Total Active Harm Power: " + String(Monitoring.GetTotalActiveHarPower()) + "W");
      Log.println("Reactive Power => A: " + String(Monitoring.GetReactivePowerA()) + "VARS, B: " + String(Monitoring.GetReactivePowerB()) + "VARS, C: " + String(Monitoring.GetReactivePowerC()) + "VARS");
      Log.println("Apparent Power => A: " + String(Monitoring.GetApparentPowerA()) + "VA, B: " + String(Monitoring.GetApparentPowerB()) + "VA, C: " + String(Monitoring.GetApparentPowerC()) + "VA");
      Log.println("Phase => A: " + String(Monitoring.GetPhaseA()) + "°, B: " + String(Monitoring.GetPhaseB()) + "°, C: " + String(Monitoring.GetPhaseC()) + "°");
      Log.println("PF => A: " + String(Monitoring.GetPowerFactorA()) + ", B: " + String(Monitoring.GetPowerFactorB()) + ", C: " + String(Monitoring.GetPowerFactorC()));

      Log.println();
    }
    tickPrintData = currentMillis;
  }

  // delay(50);
}

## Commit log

2019-04-04 Add Hardware Files
    [ESP-Power-Monitoring.PrjPcb, Relay.SchDoc, Top.SchDoc]
2019-04-05 Add ATM90E32AS
    [ATM90E32AS.SchDoc, ESP-Power-Monitoring.PrjPcb, Top.SchDoc]
2019-04-08 Update PCB
    [ATM90E32AS.SchDoc, ESP-Power-Monitoring.PrjPcb, ESP8266.SchDoc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]
2019-04-10 Finish PCB routing, send to fab
    [ATM90E32AS.SchDoc, ESP-Power-Monitoring.PrjPcb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]
2019-05-02 Update Hardware and Software
    [ATM90E32AS.SchDoc, Bill of Materials-ESP-Power-Monitoring.xls, ESP-Power-Monitoring.PrjPcb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]
2019-06-08 Update Software, remove LED because kill SPI bus
2019-06-28 Add API Rest for wifimanager and reset board
2019-07-15 Add cos phy in power compute
2019-07-29 fix bug in mode tri 2
    [ATM90E32.cpp]
2019-08-02 Fix bug of state of relay
    [settings.h]
2019-10-12 Auto stash before merge of "master" and "ESP-Power-Monitoring/master"
2020-06-07 add LED
2020-06-07 Add ticker for LED
2020-06-07 Add iGain for multiple current clamp
2020-06-07 Add current configuration on WifiManager
